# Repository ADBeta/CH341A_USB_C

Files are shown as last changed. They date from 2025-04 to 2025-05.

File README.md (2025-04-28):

# CH341a USB-C Breakout Board with UART and Programmer Pinouts

## Description
A Breakout Board for the CH341a USB UART, I2C and SPI Device, used for
programming SPI Flash Storage or I2C EEPROM, but with USB-C Connector
rather than the USB-A Male of the generic `Black Edition` Board.

<div style="display: flex; align-items: center; gap: 10px;">
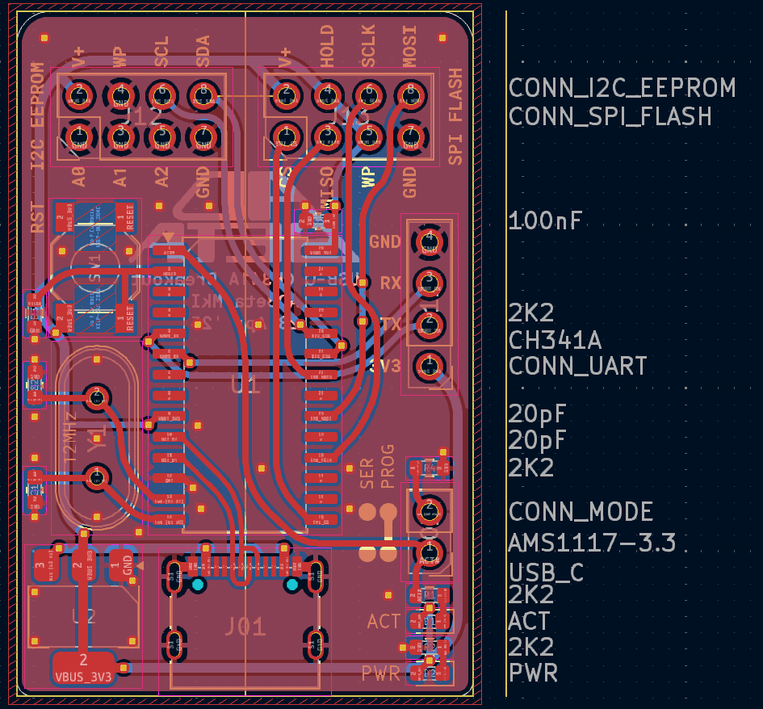
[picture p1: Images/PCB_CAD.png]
CAD
  <br>
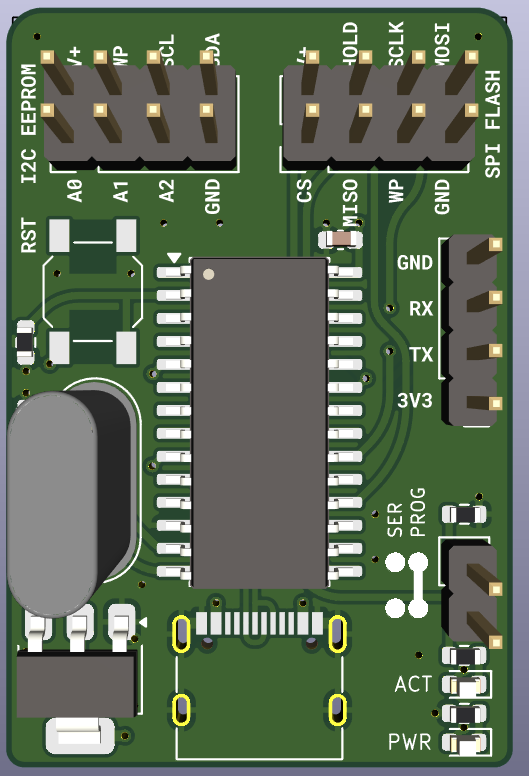
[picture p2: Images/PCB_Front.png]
Front
  
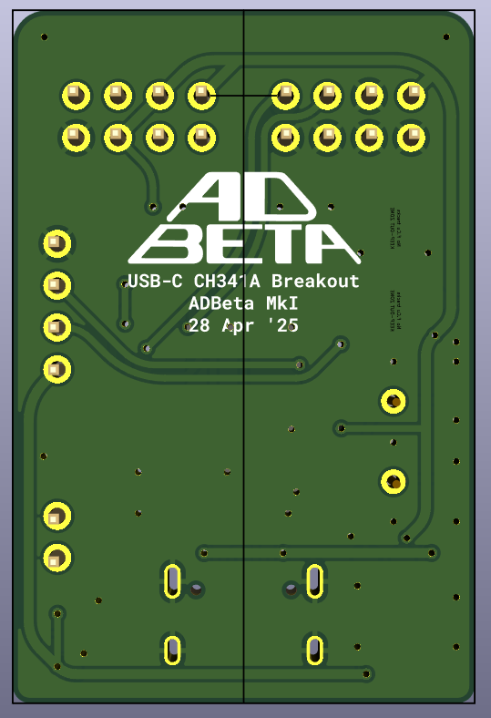
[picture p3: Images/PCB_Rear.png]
Rear
  
</div>  

## Parts List
```
D1      0603 Red LED
D2      0603 Red LED

R1      0603 2K2
R2      0603 2K2
R3      0603 2K2
R4      0603 2K2

C1      0603 20pF
C2      0603 20pF
C3      0603 100nF

U1      CH341a
U2      AMS1117-3.3

Y1      HC49S 12MHz XTAL
```

----
Copyright (c) ADBeta 2025

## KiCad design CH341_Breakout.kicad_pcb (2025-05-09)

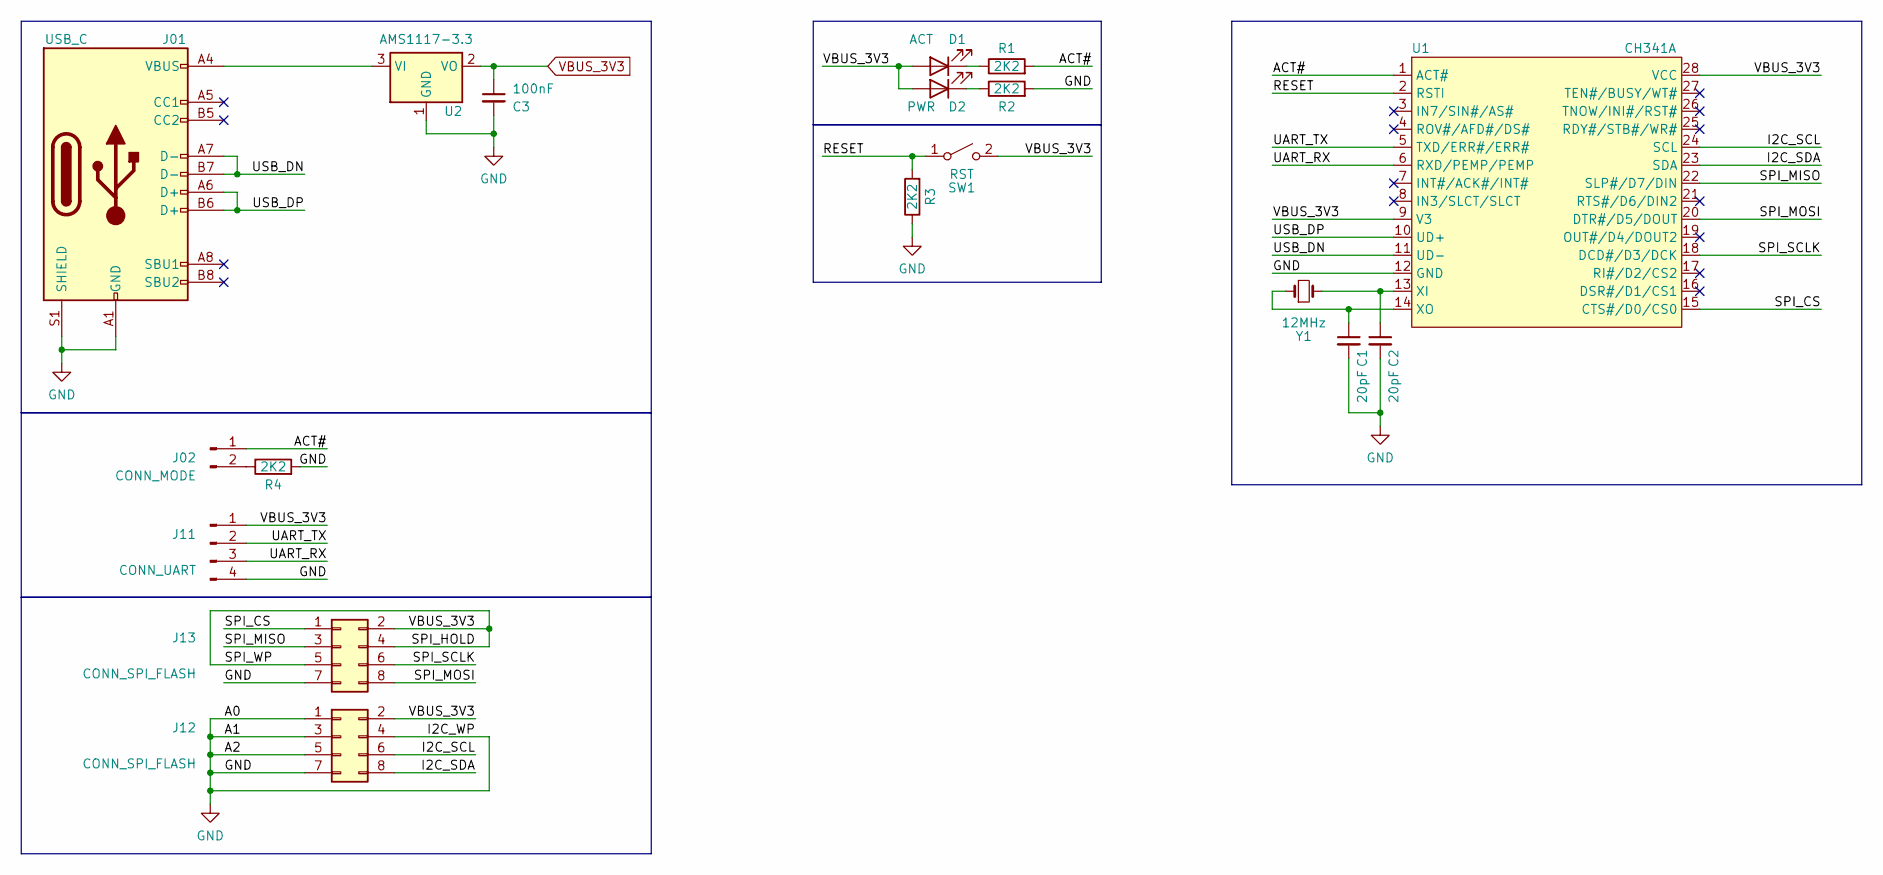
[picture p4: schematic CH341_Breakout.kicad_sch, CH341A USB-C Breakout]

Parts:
C1, C2: 20pF; C_0603_1608Metric
C3: 100nF; C_0603_1608Metric
D1: ACT; LED_0603_1608Metric
D2: PWR; LED_0603_1608Metric
J01: USB_C; USB_C_Receptacle_G-Switch_GT-USB-7010ASV
J02: CONN_MODE; PinHeader_1x02_P2.54mm_Vertical
J11: CONN_UART; PinHeader_1x04_P2.54mm_Vertical
J12, J13: CONN_SPI_FLASH
R1, R2, R3, R4: 2K2; R_0603_1608Metric
SW1: RST; SW_SPST_SKQG_WithoutStem
U1: CH341A; SOIC-28W_7.5x17.9mm_P1.27mm
U2: AMS1117-3.3; SOT-223-3_TabPin2
Y1: 12MHz; Crystal_HC49-U_Vertical

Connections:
/ACT#: J02.1, R1.2, U1.1 (ACT#)
/I2C_SCL: J12.6, U1.24 (SCL)
/I2C_SDA: J12.8, U1.23 (SDA)
/RESET: R3.2, SW1.1 (A), U1.2 (RSTI)
/SPI_CS: J13.1, U1.15 (CTS#/D0/CS0)
/SPI_MISO: J13.3, U1.22 (SLP#/D7/DIN)
/SPI_MOSI: J13.8, U1.20 (DTR#/D5/DOUT)
/SPI_SCLK: J13.6, U1.18 (DCD#/D3/DCK)
/UART_RX: J11.3, U1.6 (RXD/PEMP/PEMP)
/UART_TX: J11.2, U1.5 (TXD/ERR#/ERR#)
/USB_DN: J01.A7 (D-), J01.B7 (D-), U1.11 (UD-)
/USB_DP: J01.A6 (D+), J01.B6 (D+), U1.10 (UD+)
GND: C1.2, C2.2, C3.2, J01.A1 (GND), J01.A12 (GND), J01.B1 (GND), J01.B12 (GND), J01.S1 (SHIELD), J11.4, J12.1, J12.3, J12.4, J12.5, J12.7, J13.7, R2.2, R3.1, R4.2, U1.12 (GND), U2.1 (GND)
unnamed: D1.1 (K), R1.1
unnamed: D2.1 (K), R2.1
unnamed: J02.2, R4.1
unnamed: C2.1, U1.13 (XI), Y1.2
unnamed: C1.1, U1.14 (XO), Y1.1
unnamed: J01.A4 (VBUS), J01.A9 (VBUS), J01.B4 (VBUS), J01.B9 (VBUS), U2.3 (VI)
VBUS_3V3: C3.1, D1.2 (A), D2.2 (A), J11.1, J12.2, J13.2, J13.4, J13.5, SW1.2 (B), U1.9 (V3), U1.28 (VCC), U2.2 (VO)

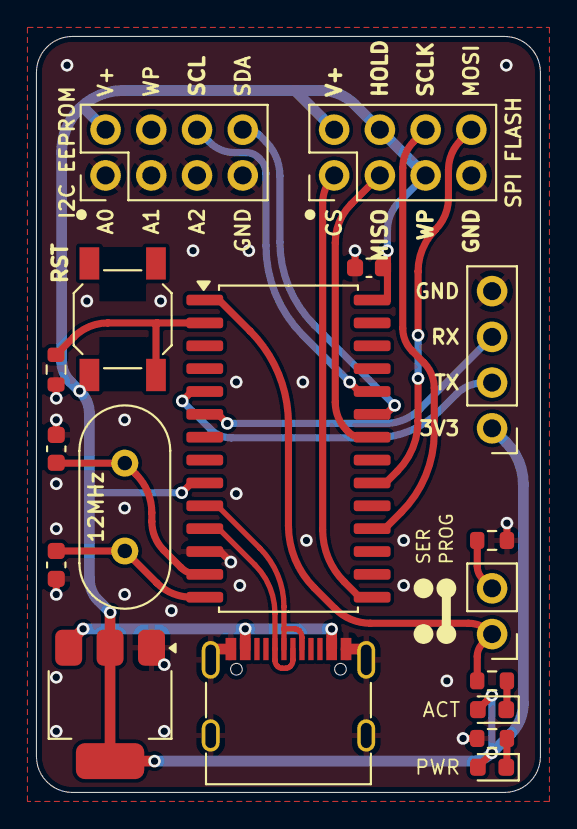
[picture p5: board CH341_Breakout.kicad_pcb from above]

Board: 2 copper layers, 28.0 x 42.0 mm, 18 parts (0 on the bottom side), 20 nets.

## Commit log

2025-04-24 Added USB C and other bits
    [CH341_Breakout.kicad_pcb, CH341_Breakout.kicad_sch]
2025-04-26 Started MkI PCB Design
    [CH341_Breakout.kicad_pcb, CH341_Breakout.kicad_sch]
2025-04-28 Finished MkI Board
    [CH341_Breakout.kicad_pcb]
2025-05-09 Finalised, built and tested
    [CH341_Breakout.kicad_pcb, CH341_Breakout.kicad_sch]
